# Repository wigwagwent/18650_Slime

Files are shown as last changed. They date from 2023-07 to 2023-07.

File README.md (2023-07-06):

# slimevr_pcb
A PCB design the size of a 18650 battery that supports the BMI160 designed for SlimeVR full-body trackers

- [18650_Slime-Main](/hardware/18650_Slime_main/) - A fully custom PCB that handles the IMU.

  Unlike most of the SlimeVR community, it uses the ESP32-C3, a newer and more
  powerful chip. Designed to be a more powerful development platform, as it natively
  supports JTAG debugging over USB, more compilers and languages, including Rust,
  and supports Bluetooth LE v5.0.
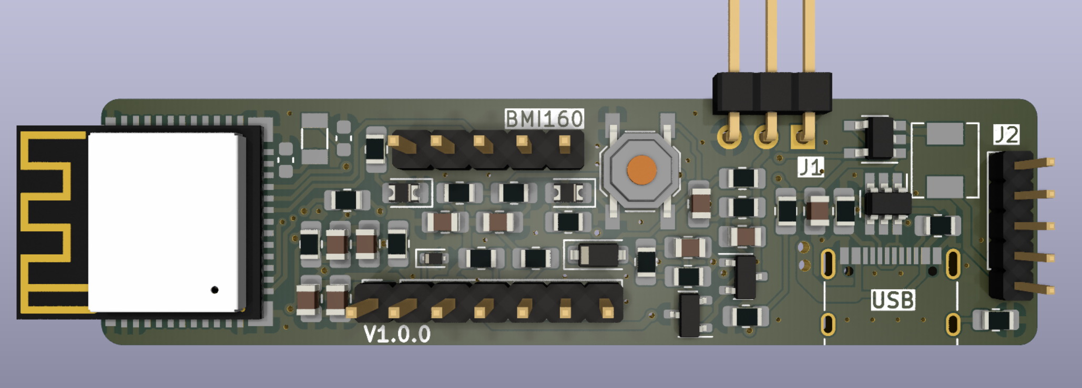
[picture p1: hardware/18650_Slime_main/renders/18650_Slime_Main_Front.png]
3d render
  

- [18650_Slime-Battery](/hardware/18650_Slime_battery/) - Combines fast charging with protection
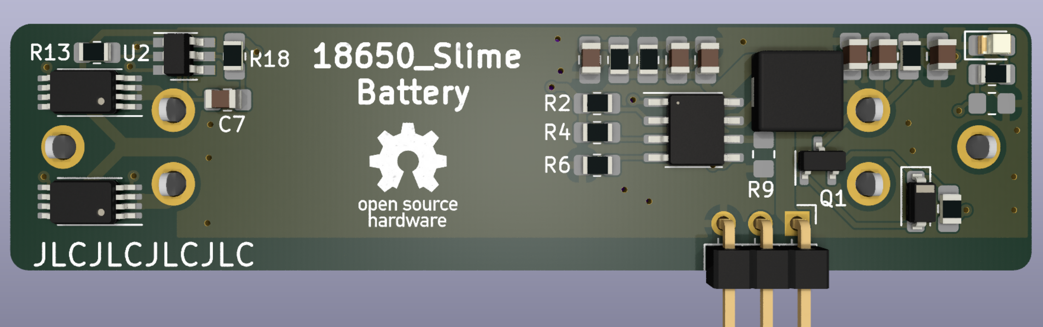
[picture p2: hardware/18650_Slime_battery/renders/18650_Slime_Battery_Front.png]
3d render
  
  
  It can be used with other boards that want an 18650 cell with a built in charge controller.

## License
**This hardware is licensed under the CERN-OHL-P v2 license**, which is a permissive,
non-viral and non-reciprocal open hardware license. Unlike software licenses like
MIT and Apache 2.0, it better handles the nuances of hardware and protects both
the licensor and licensee from patent lawsuits.

**Unless you explicitly state otherwise, any contribution intentionally submitted
for inclusion in this work by you, shall be licensed as above, without any
additional terms or conditions.**

### Conveying notice of License
Note that as part of the CERN-OHL-P v2 license, recipients of manufactured
hardware must also receive notice of the above license. One such
method of conveying the notice is to include a link to the original source repo,
or printing "Licensed under CERN-OHL-P v2" on the PCB silkscreen. For more info,
see [here](https://ohwr.org/project/cernohl/wikis/uploads/8a6b5d01f71c207c49493e4d114d61e6/cern_ohl_p_v2_howto.pdf).

This is conceptually similar to the MIT/Apache 2.0 Licenses, where the original
license must still be included as a notice even when the source is modified and
subsequently relicensed under different terms.

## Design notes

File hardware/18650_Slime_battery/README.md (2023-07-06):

# 18650 SlimeVR Battery
This PCB is designed to be about the same size as a 18650 cell and contains all the charging and protection
circuitry for that one cell. It has under/over voltage, over current through a 350mA resettable fuse, and short 
circuit protection. It supports charging rates up to 3A with the current setting being 2.1A.

## Renders
Front
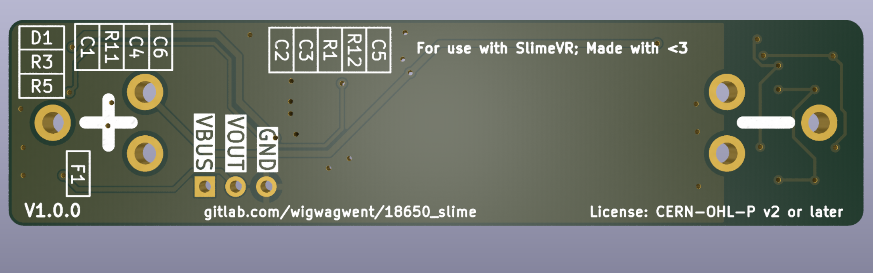
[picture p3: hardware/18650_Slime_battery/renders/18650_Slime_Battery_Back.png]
Back

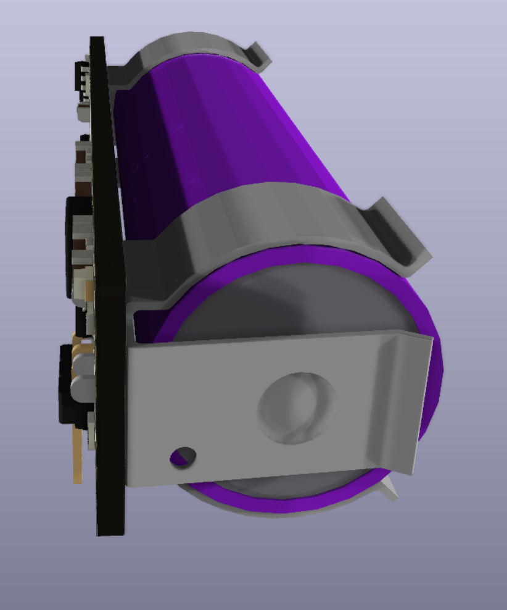
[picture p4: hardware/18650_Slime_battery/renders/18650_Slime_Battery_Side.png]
Side

Schematic Battery Board
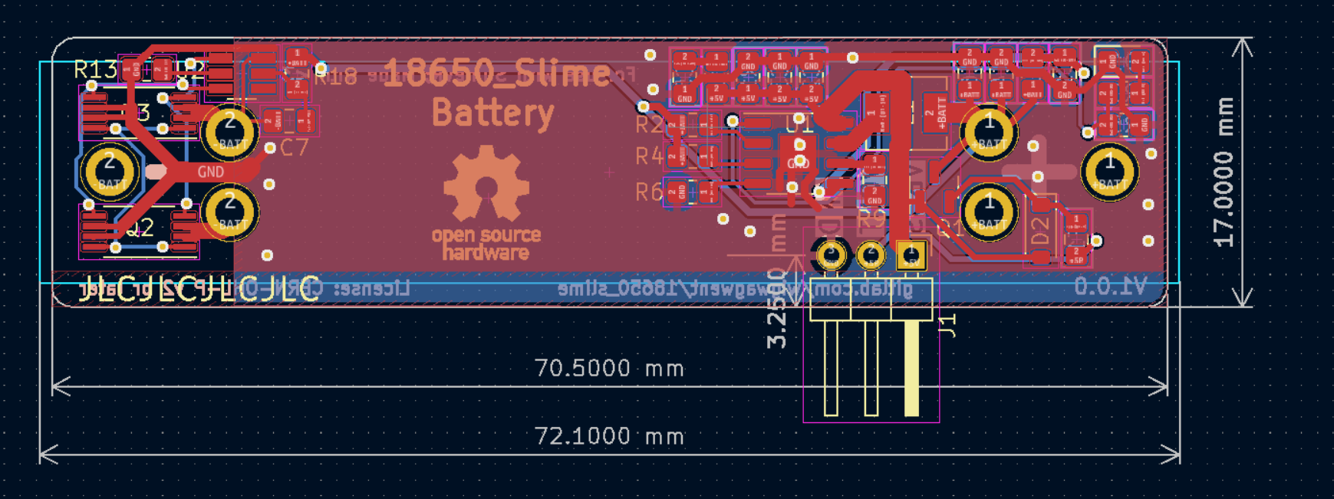
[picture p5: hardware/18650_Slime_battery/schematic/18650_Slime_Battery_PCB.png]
PCB


## Changelog
A description of the changes in each revision can be found [here](CHANGELOG.md).

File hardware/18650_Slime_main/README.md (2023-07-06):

# 18650 SlimeVR
This PCB is designed to be about the same size as a 18650 cell once fully assembled
and stacked. This is a stacked board design but in theory, all the hardware should
be able to fit onto one board but is separated to two boards.

## Useful Information
- IMU: BMI160 Module
- ESP32-C3 main processor

## Renders
Front
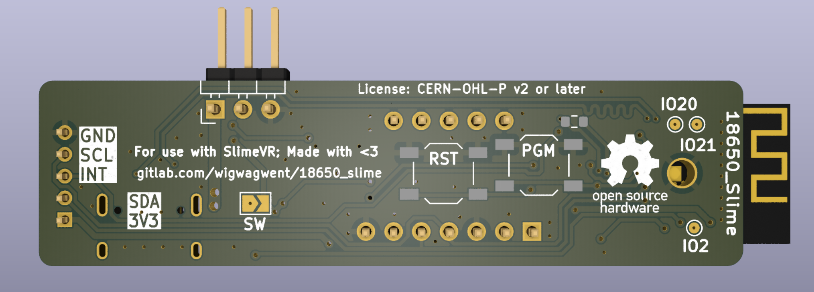
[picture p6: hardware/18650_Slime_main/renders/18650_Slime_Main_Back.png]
Back

Schematic Main Board
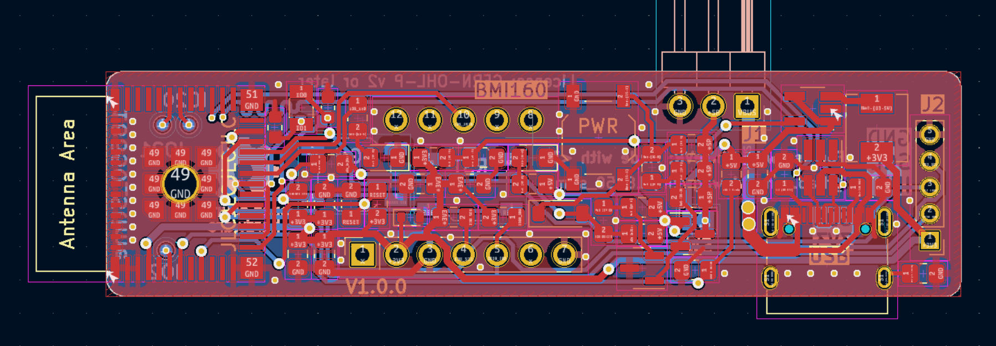
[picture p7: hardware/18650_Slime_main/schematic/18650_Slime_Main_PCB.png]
PCB


## Changelog
A description of the changes in each revision can be found [here](CHANGELOG.md).

## Credits
The schematic was based on version 3.0 of the ferrous_slime.
Big thanks to TheButlah for all the work he put into this schematic and into slimevr.
Also big thanks to Mosaic-Industries for there push button reference design
Final thanks to this github project that implements a usefull parts search for jlcpcb

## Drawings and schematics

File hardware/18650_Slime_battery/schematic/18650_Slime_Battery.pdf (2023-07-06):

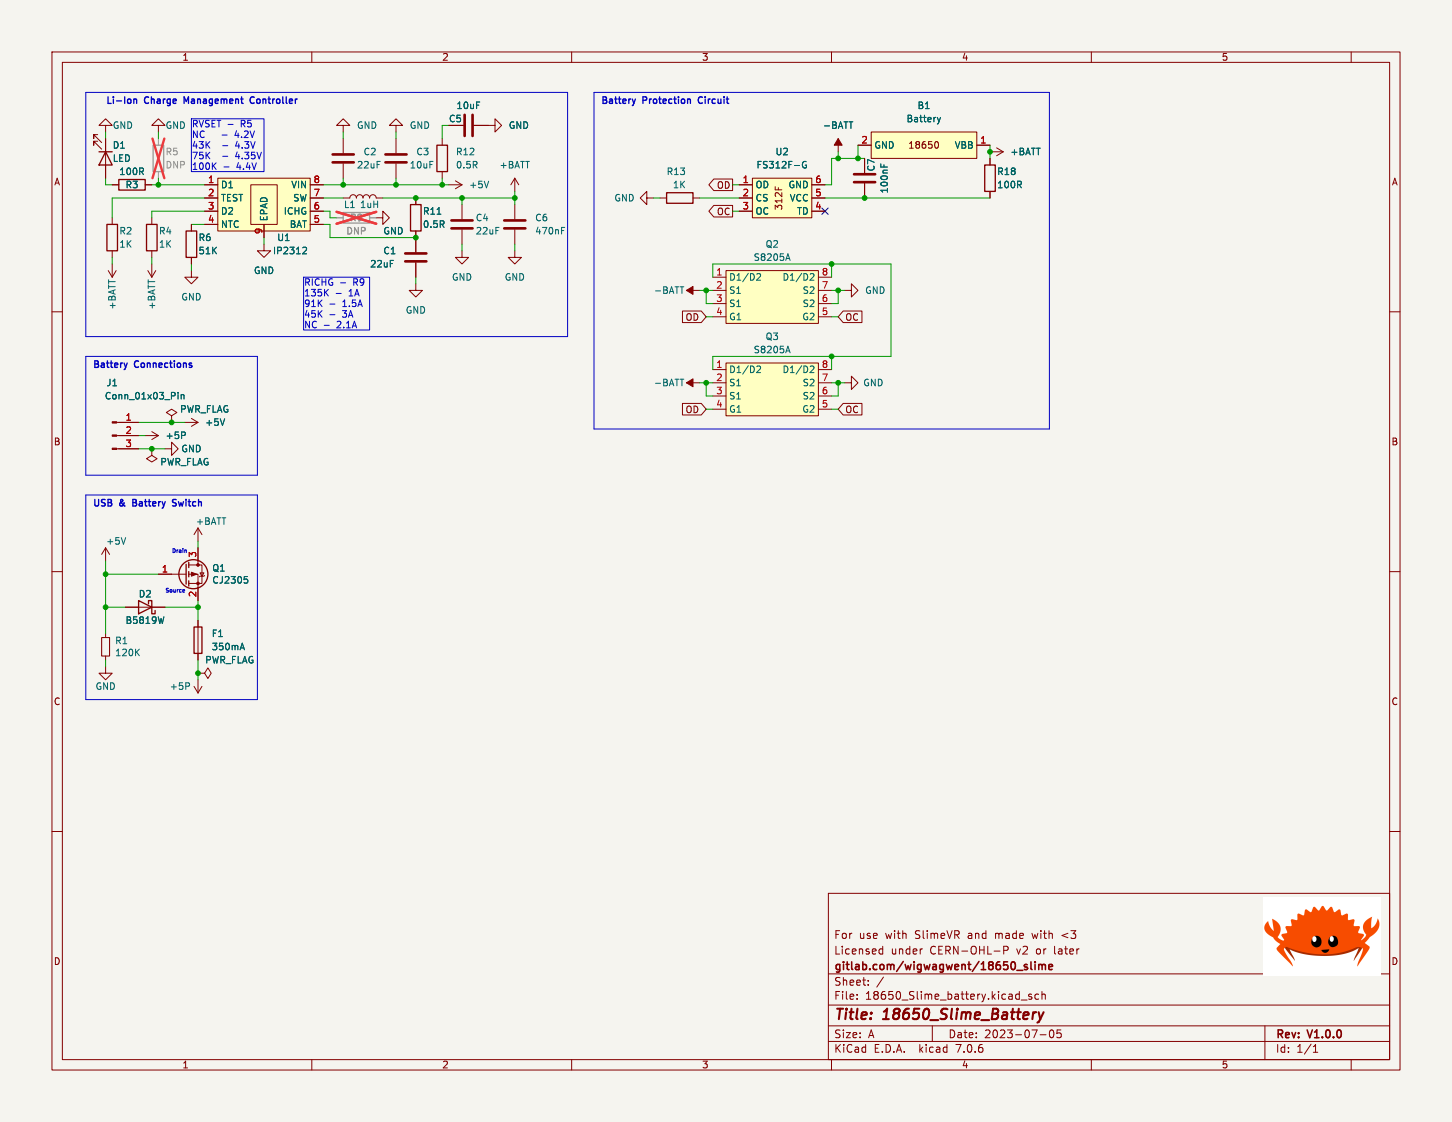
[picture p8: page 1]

File: 18650_Slime_battery.kicad_sch Sheet: / gitlab.com/wigwagwent/18650_slime

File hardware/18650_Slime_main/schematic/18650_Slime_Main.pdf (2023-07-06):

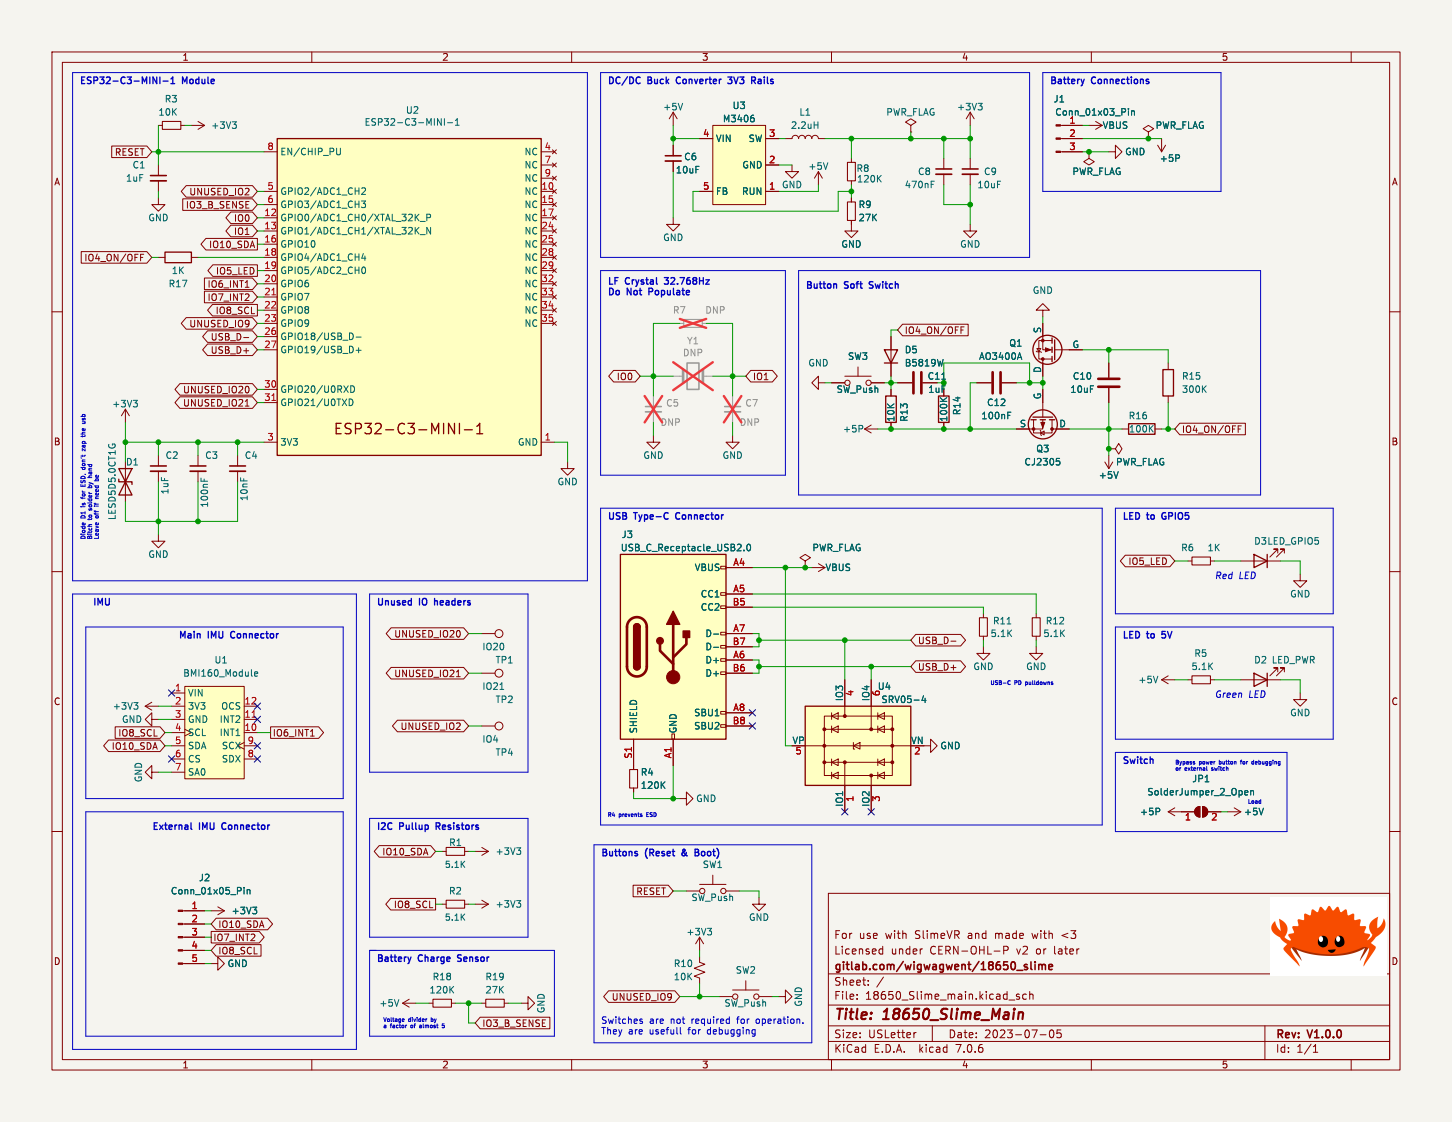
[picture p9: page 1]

DC/DC Buck Converter 3V3 Rails
+5V GND

U3 M3406RUN 1 GND 2 SW 3 VIN 4 FB 5 C6

File: 18650_Slime_main.kicad_sch Sheet: / gitlab.com/wigwagwent/18650_slime

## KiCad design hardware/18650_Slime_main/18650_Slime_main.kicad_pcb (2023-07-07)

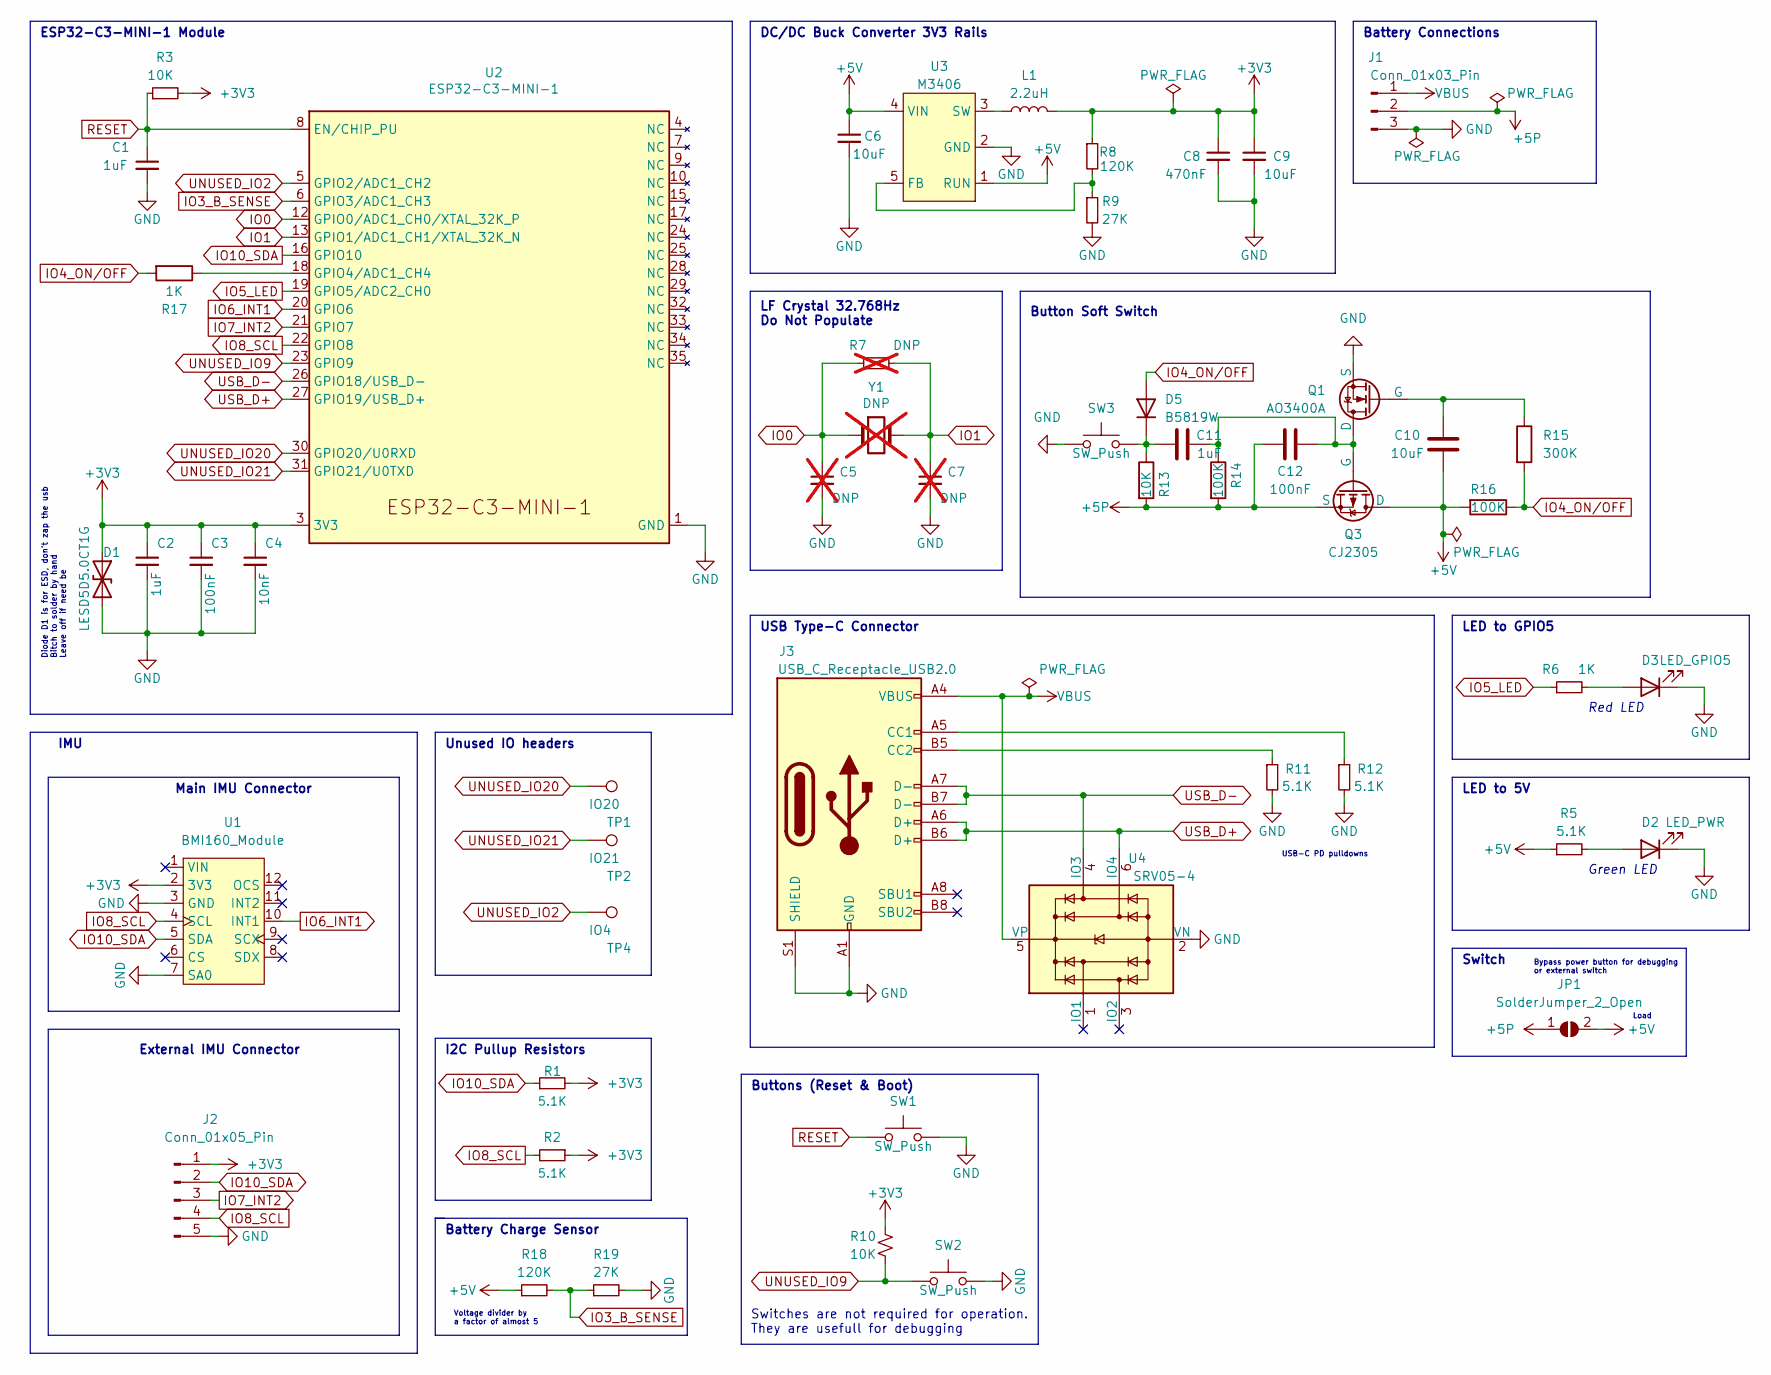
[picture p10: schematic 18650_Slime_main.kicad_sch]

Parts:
C1, C2, C11: 1uF; C_0805_2012Metric_Pad1.18x1.45mm_HandSolder; LCSC C28323
C3, C12: 100nF; C_0805_2012Metric_Pad1.18x1.45mm_HandSolder; LCSC C49678
C4: 10nF; C_0805_2012Metric_Pad1.18x1.45mm_HandSolder; LCSC C1710
C5, C7: DNP; C_0603_1608Metric; LCSC DNP; not fitted
C6, C9, C10: 10uF; C_0805_2012Metric_Pad1.18x1.45mm_HandSolder; LCSC C15850
C8: 470nF; C_0805_2012Metric_Pad1.18x1.45mm_HandSolder; LCSC C13967
D1: LESD5D5.0CT1G; D_SOD-523; LCSC C5199850
D2: LED_PWR; D_0805_2012Metric_Pad1.15x1.40mm_HandSolder; LCSC C688883
D3: LED_GPIO5; D_0805_2012Metric_Pad1.15x1.40mm_HandSolder; LCSC C84256
D5: B5819W; D_SOD-123; LCSC C8598
J1: Conn_01x03_Pin; PinHeader_1x03_P2.54mm_Horizontal; LCSC DNP
J2: Conn_01x05_Pin; PinHeader_1x05_P2.00mm_Vertical; LCSC DNP
J3: USB_C_Receptacle_USB2.0; USB_C_Receptacle_XKB_U262-16XN-4BVC11; LCSC C319148
JP1: SolderJumper_2_Open; SolderJumper-2_P1.3mm_Open_TrianglePad1.0x1.5mm; LCSC DNP
L1: 2.2uH; SMMS0420; LCSC C133191
Q1: AO3400A; SOT-23; LCSC C347475
Q3: CJ2305; SOT-23; LCSC C8549
R1, R2, R5, R11, R12: 5.1K; R_0805_2012Metric_Pad1.20x1.40mm_HandSolder; LCSC C27834
R3, R10, R13: 10K; R_0805_2012Metric_Pad1.20x1.40mm_HandSolder; LCSC C17414
R6, R17: 1K; R_0805_2012Metric_Pad1.20x1.40mm_HandSolder; LCSC C17513
R7: DNP; R_0603_1608Metric; LCSC DNP; not fitted
R8, R18: 120K; R_0805_2012Metric_Pad1.20x1.40mm_HandSolder; LCSC C17436
R9, R19: 27K; R_0805_2012Metric_Pad1.20x1.40mm_HandSolder; LCSC C17593
R14, R16: 100K; R_0805_2012Metric_Pad1.20x1.40mm_HandSolder; LCSC C149504
R15: 300K; R_0805_2012Metric_Pad1.20x1.40mm_HandSolder; LCSC C17616
SW1, SW2, SW3: SW_Push; TSC005A1732A; LCSC C2888878
TP1: IO20; TestPoint_Pad_D1.0mm; LCSC DNP
TP2: IO21; TestPoint_Pad_D1.0mm; LCSC DNP
TP4: IO4; TestPoint_Pad_D1.0mm; LCSC DNP
U1: BMI160_Module; BMI160; LCSC DNP
U2: ESP32-C3-MINI-1; ESP32-C3-MINI-1_HandSoldering; LCSC C2838502
U3: M3406; SOT-23-5_HandSoldering; LCSC C83224
U4: SRV05-4; SOT-23-6_Handsoldering; LCSC C558418
Y1: DNP; Crystal_SMD_3215-2Pin_3.2x1.5mm; LCSC DNP; not fitted

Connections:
+3V3: C2.1, C3.1, C4.1, C8.1, C9.1, D1.1 (A1), J2.1, L1.2, R1.2, R2.1, R3.2, R8.1, R10.1, U1.2 (3V3), U2.3 (3V3)
+5P: C12.1, J1.2, JP1.1 (A), Q3.3 (S), R13.2, R14.2
+5V: C6.1, C10.2, JP1.2 (B), Q3.1 (D), R5.1, R16.2, R18.1, U3.1 (RUN), U3.4 (VIN)
GND: C1.2, C2.2, C3.2, C4.2, C5.2, C6.2, C7.2, C8.2, C9.2, D1.2 (A2), D2.1 (K), D3.1 (K), J1.3, J2.5, J3.A1 (GND), J3.A12 (GND), J3.B1 (GND), J3.B12 (GND), J3.S1 (SHIELD), Q1.3 (S), R9.2, R11.2, R12.2, R19.2, SW1.2, SW2.2, SW3.1, U1.3 (GND), U1.7 (SA0), U2.1 (GND), U2.2 (GND), U2.11 (GND), U2.14 (GND), U2.36 (GND), U2.37 (GND), U2.38 (GND), U2.39 (GND), U2.40 (GND), U2.41 (GND), U2.42 (GND), U2.43 (GND), U2.44 (GND), U2.45 (GND), U2.46 (GND), U2.47 (GND), U2.48 (GND), U2.49 (GND), U2.50 (GND), U2.51 (GND), U2.52 (GND), U2.53 (GND), U3.2 (GND), U4.2 (VN)
IO0: C5.1, R7.1, U2.12 (GPIO0/ADC1_CH0/XTAL_32K_P), Y1.1
IO1: C7.1, R7.2, U2.13 (GPIO1/ADC1_CH1/XTAL_32K_N), Y1.2
IO3_B_SENSE: R18.2, R19.1, U2.6 (GPIO3/ADC1_CH3)
IO4_ON/OFF: D5.2 (A), R15.2, R16.1, R17.2
IO5_LED: R6.1, U2.19 (GPIO5/ADC2_CH0)
IO6_INT1: U1.10 (INT1), U2.20 (GPIO6)
IO7_INT2: J2.3, U2.21 (GPIO7)
IO8_SCL: J2.4, R2.2, U1.4 (SCL), U2.22 (GPIO8)
IO10_SDA: J2.2, R1.1, U1.5 (SDA), U2.16 (GPIO10)
unnamed: D2.2 (A), R5.2
unnamed: D3.2 (A), R6.2
unnamed: C11.2, D5.1 (K), R13.1, SW3.2
unnamed: J3.A5 (CC1), R12.1
unnamed: J3.B5 (CC2), R11.1
unnamed: C11.1, C12.2, Q1.1 (D), Q3.2 (G), R14.1
unnamed: C10.1, Q1.2 (G), R15.1
unnamed: R17.1, U2.18 (GPIO4/ADC1_CH4)
unnamed: R8.2, R9.1, U3.5 (FB)
unnamed: L1.1, U3.3 (SW)
RESET: C1.1, R3.1, SW1.1, U2.8 (EN/CHIP_PU)
UNUSED_IO2: TP4.1, U2.5 (GPIO2/ADC1_CH2)
UNUSED_IO9: R10.2, SW2.1, U2.23 (GPIO9)
UNUSED_IO20: TP1.1, U2.30 (GPIO20/U0RXD)
UNUSED_IO21: TP2.1, U2.31 (GPIO21/U0TXD)
USB_D+: J3.A6 (D+), J3.B6 (D+), U2.27 (GPIO19/USB_D+), U4.6 (IO4)
USB_D-: J3.A7 (D-), J3.B7 (D-), U2.26 (GPIO18/USB_D-), U4.4 (IO3)
VBUS: J1.1, J3.A4 (VBUS), J3.A9 (VBUS), J3.B4 (VBUS), J3.B9 (VBUS), U4.5 (VP)

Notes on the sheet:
LED to 5V
Load
I2C Pullup Resistors
Diode D1 is for ESD, don't zap the usb Bitch to solder by hand Leave off if need be
Voltage divider by a factor of almost 5
LF Crystal 32.768Hz Do Not Populate
External IMU Connector
USB-C PD pulldowns
IMU
DC/DC Buck Converter 3V3 Rails
Buttons (Reset & Boot)
Main IMU Connector
Battery Connections
Battery Charge Sensor
Bypass power button for debugging or external switch
Button Soft Switch
Unused IO headers
LED to GPIO5
Switches are not required for operation. They are usefull for debugging
ESP32-C3-MINI-1 Module
Green LED
USB Type-C Connector
Red LED
Switch

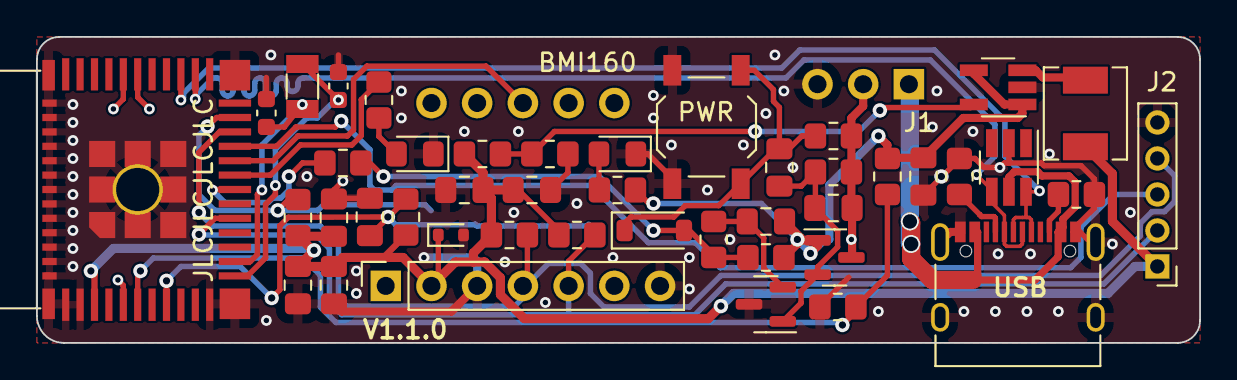
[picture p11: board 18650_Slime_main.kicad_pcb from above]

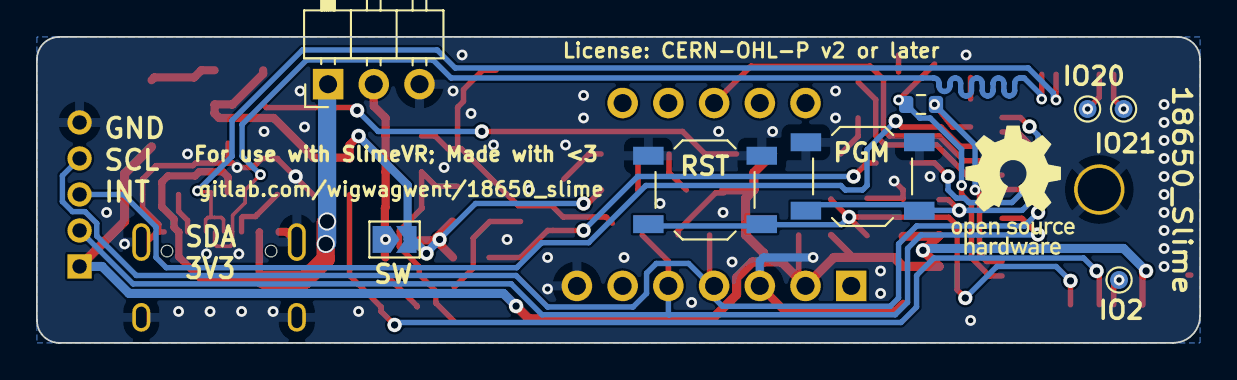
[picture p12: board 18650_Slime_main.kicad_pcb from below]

Board: 2 copper layers, 64.6 x 17.0 mm, 52 parts (8 on the bottom side), 31 nets.

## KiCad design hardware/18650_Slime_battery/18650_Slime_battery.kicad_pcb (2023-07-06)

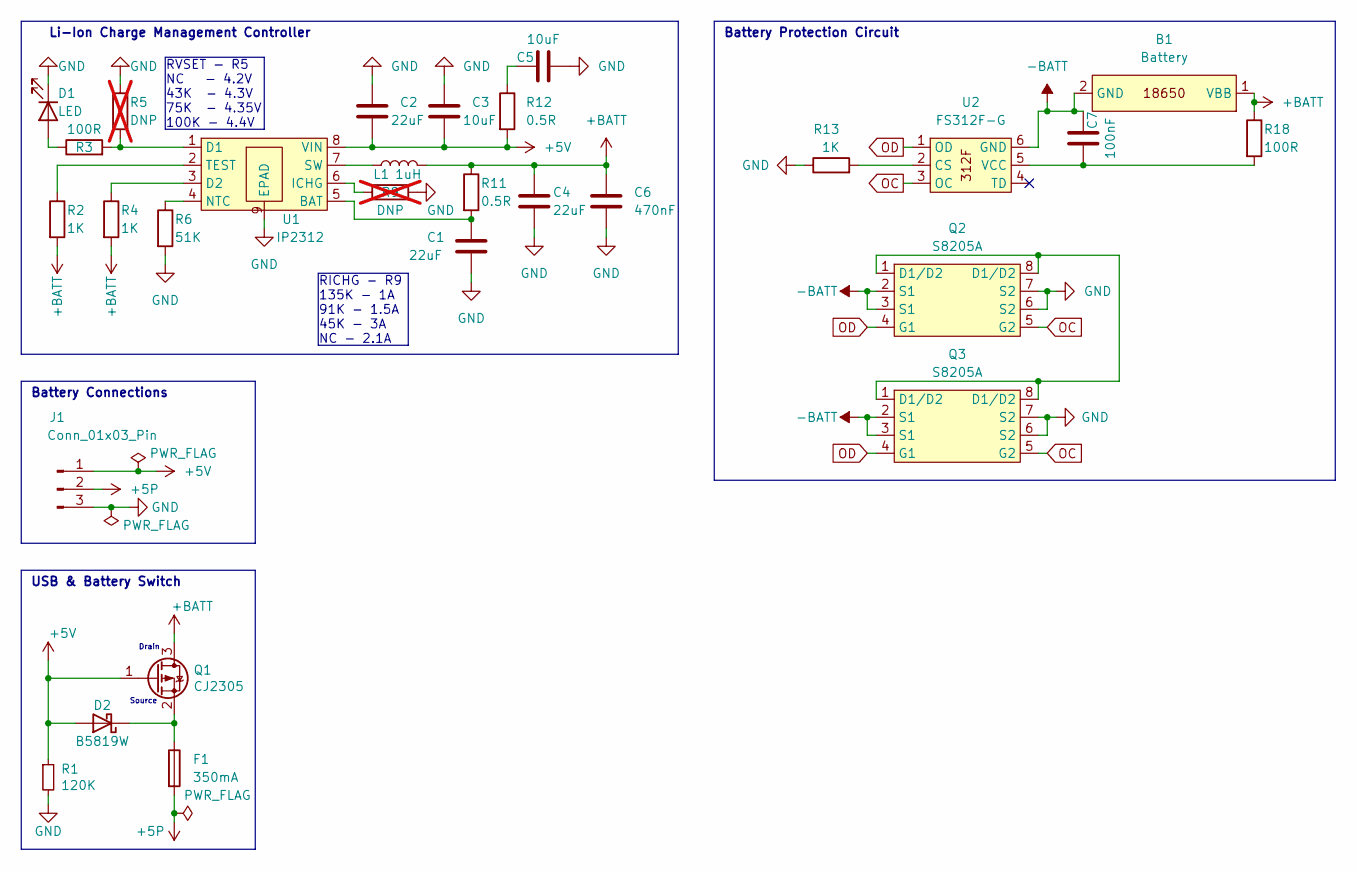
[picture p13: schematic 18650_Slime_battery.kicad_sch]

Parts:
B1: Battery; 18650_Battery; LCSC DNP
C1, C2, C4: 22uF; C_0805_2012Metric_Pad1.18x1.45mm_HandSolder; LCSC C45783
C3, C5: 10uF; C_0805_2012Metric_Pad1.18x1.45mm_HandSolder; LCSC C15850
C6: 470nF; C_0805_2012Metric_Pad1.18x1.45mm_HandSolder; LCSC C13967
C7: 100nF; C_0805_2012Metric_Pad1.18x1.45mm_HandSolder; LCSC C49678
D1: LED; LED_0805_2012Metric_Pad1.15x1.40mm_HandSolder; LCSC C84256
D2: B5819W; D_SOD-123; LCSC C8598
F1: 350mA; Fuse_0805_2012Metric_Pad1.15x1.40mm_HandSolder; LCSC C269103
J1: Conn_01x03_Pin; PinHeader_1x03_P2.54mm_Horizontal
L1: 1uH; SMMS0420; LCSC C133189
Q1: CJ2305; SOT-23; LCSC C8549
Q2, Q3: S8205A; TSSOP-8_4.4x3mm_P0.65mm; LCSC C436910
R1: 120K; R_0805_2012Metric_Pad1.20x1.40mm_HandSolder; LCSC C17436
R2, R4, R13: 1K; R_0805_2012Metric_Pad1.20x1.40mm_HandSolder; LCSC C17513
R3, R18: 100R; R_0805_2012Metric_Pad1.20x1.40mm_HandSolder; LCSC C17408
R5, R9: DNP; R_0805_2012Metric_Pad1.20x1.40mm_HandSolder; LCSC DNP; not fitted
R6: 51K; R_0805_2012Metric_Pad1.20x1.40mm_HandSolder; LCSC C17737
R11, R12: 0.5R; R_0805_2012Metric_Pad1.20x1.40mm_HandSolder; LCSC C327217
U1: IP2312; LCSC C605433
U2: FS312F-G; SOT-23-6_Handsoldering; LCSC C82736

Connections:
+5P: F1.2, J1.2
+5V: C2.2, C3.2, D2.2 (A), J1.1, Q1.1 (G), R1.1, R12.2, U1.8 (VIN)
+BATT: B1.1 (VBB), C4.1, C6.1, L1.2, Q1.3 (D), R2.2, R4.2, R11.1, R18.1
-BATT: B1.2 (GND), C7.2, Q2.2 (S1), Q2.3 (S1), Q3.2 (S1), Q3.3 (S1), U2.6 (GND)
GND: C1.2, C2.1, C3.1, C4.2, C5.1, C6.2, D1.1 (K), J1.3, Q2.6 (S2), Q2.7 (S2), Q3.6 (S2), Q3.7 (S2), R1.2, R5.1, R6.2, R9.2, R13.1, U1.9 (EPAD)
unnamed: C5.2, R12.1
unnamed: D1.2 (A), R3.1
unnamed: D2.1 (K), F1.1, Q1.2 (S)
unnamed: Q2.1 (D1/D2), Q2.8 (D1/D2), Q3.1 (D1/D2), Q3.8 (D1/D2)
unnamed: C1.1, R11.2, U1.5 (BAT)
unnamed: R3.2, R5.2, U1.1 (D1)
unnamed: R4.1, U1.3 (D2)
unnamed: R9.1, U1.6 (ICHG)
unnamed: R6.1, U1.4 (NTC)
unnamed: L1.1, U1.7 (SW)
unnamed: R2.1, U1.2 (TEST)
unnamed: R13.2, U2.2 (CS)
unnamed: C7.1, R18.2, U2.5 (VCC)
OC: Q2.5 (G2), Q3.5 (G2), U2.3 (OC)
OD: Q2.4 (G1), Q3.4 (G1), U2.1 (OD)

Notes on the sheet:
RICHG - R9 135K - 1A 91K - 1.5A 45K - 3A NC - 2.1A
Battery Connections
RVSET - R5 NC - 4.2V 43K - 4.3V 75K - 4.35V 100K - 4.4V
Battery Protection Circuit
Li-Ion Charge Management Controller
Drain
Source
USB & Battery Switch

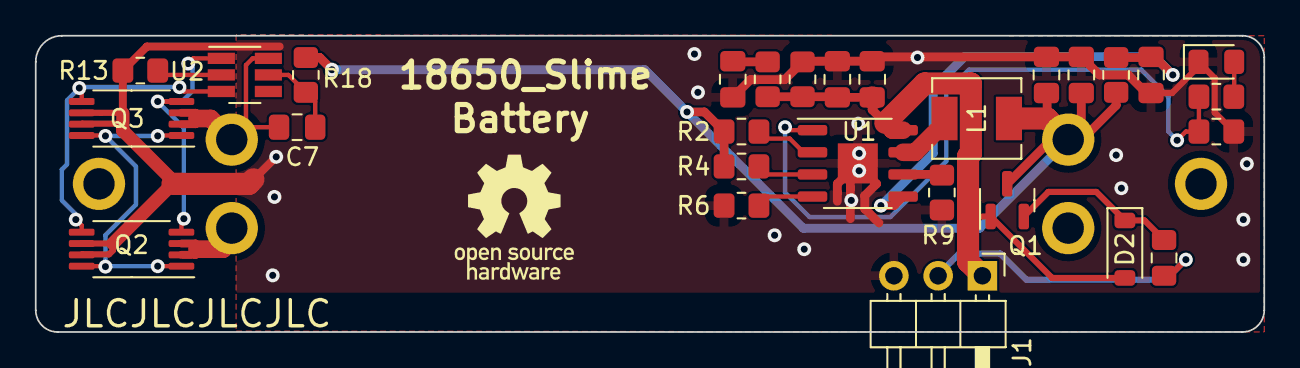
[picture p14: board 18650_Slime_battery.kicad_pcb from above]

Board: 2 copper layers, 70.5 x 17.0 mm, 29 parts (1 on the bottom side), 20 nets.

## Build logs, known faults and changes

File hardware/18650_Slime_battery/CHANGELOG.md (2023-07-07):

# Changelog

## How the Version Works
The version will look like this: vx.y.z

The respective number will increase if one of the changes below happen
- x (Major Change) is any major change like designing a new PCB
- y (Stencil Change) is any change that needs a new stencil
- z (Minor Change) is any minor change, like silkscreen

**Note:** Not every minor revision will be tested, they will be listed below. 
Only very small changes are allowed so they should work if the stencil change worked.

## v1.0.0
- Split this into its own kicad project
- Removed any components not for battery managment
- fixes issues
	-#2 0805 passives
	-#3 Make trace spacing bigger
	-#4 TP4056 gets hot at 500ma
	-#6 Verify that there is undervolt protection
- Added a mounting place for battery

## v1.0.0 component update
- FS312F-G was replaced by DW01C-G [Stock]
- S8205A was replaced by MS8205A (New is not in JLCPCB parts yet) [Deprecated] 
- IP2312-4V35 was replaced by IP2312U-VSET [Stock]

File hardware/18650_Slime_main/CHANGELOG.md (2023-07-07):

# Changelog

## How the Version Works
The version will look like this: vx.y.z

The respective number will increase if one of the changes below happen
- x (Major Change) is any major change like designing a new PCB
- y (Stencil Change) is any change that needs a new stencil
- z (Minor Change) is any minor change, like silkscreen

**Note:** Not every revision will be tested, the release name will indicate if it was. 
Only very small changes are allowed so they should work if the stencil change worked.

## v0.1.0
- Split the schematic into two different boards.
- Added support for BMI160 and BMM150 and removed support for other IMUs
- Designed a new PCB to be a stacked design
- Status: Mostly worked other than soldering issue with SCL not working

## v0.1.1
- Fixed INT1 track being too small
- Improved ground plane connections above IMU
- Moved ground further away from 3v3
- Status: Untested

## v0.1.2
- Added Aux label instead of j2
- Added missing 3d models
- Removed unused footprints
- Status: Untested

## v1.0.0
- New design for board
- Removed BMM150 and made BMI160 a module
- fixes issues
	-#1 Use module instead of soldering on bmi160 on main board
	-#2 0805 passives
	-#3 Make trace spacing bigger
	-#8 Add RST and GPIO 9 button onto board
- Moved every componet (except lion managment) to this board
- Added pushbutton power instead of switch

## v1.1.0
- Removed resistor from usb shield to GND
- Fixed LCSC# for 1K resistor
-PCB Ordered

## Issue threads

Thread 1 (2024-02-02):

Components in the Antenna Keepout area

wigwagwent, 2024-02-02:
The BMS components should not be included in the antenna keepout area, the only thing that should be allowed is the battery connector and a trace going to it.

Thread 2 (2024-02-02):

Footprint Adjustments

wigwagwent, 2024-02-02:
* [ ] Inductors need the pads to be spaced a little further apart
* [ ] The charging chip has a ground pad that can not be soldered with an iron, extend the EP pad out of under the part to solder with the device in place
* [ ] Figure out how to hand solder the esp32

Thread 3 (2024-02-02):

Battery Clips

wigwagwent, 2024-02-02:
The battery clip on the positive side is a fire hazard. It should not clamp the battery because the shell is ground and the pointed nub is positive. It is a low resistance high current bridge between Batt+ and Batt- if the outer sheath of the battery gets scratched. The clips do scratch the battery. A 3D printed clip with a simple battery contact only on the end would be better. The spacing is also 5mm too large.

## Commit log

2022-12-07 Update to V0.1.1 of 18650_Slime
    [18650_Slime.kicad_pcb, 18650_Slime.kicad_sch, top_level.kicad_sch]
2022-12-08 v0.1.2 of 18650_slime
    [18650_Slime.kicad_pcb, 18650_Slime.kicad_sch, top_level.kicad_sch]
2023-06-18 inital design for next major version
    [18650_Slime.kicad_pcb, 18650_Slime.kicad_sch, 18650_Slime_battery.kicad_pcb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]
2023-06-18 V1.0.0 of the battery module done
    [18650_Slime_battery.kicad_pcb, 18650_Slime_battery.kicad_sch, 18650_Slime_main.kicad_sch]
2023-07-06 V1.0.0 Release, UNTESTED
    [18650_Slime_battery.kicad_pcb, 18650_Slime_battery.kicad_sch, 18650_Slime_main.kicad_pcb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]
2023-07-07 Minor Changes INTESTING
    [18650_Slime_battery.kicad_sch, 18650_Slime_main.kicad_pcb, 18650_Slime_main.kicad_sch]

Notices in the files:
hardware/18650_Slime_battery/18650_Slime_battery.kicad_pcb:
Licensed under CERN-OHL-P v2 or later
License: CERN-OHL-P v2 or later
